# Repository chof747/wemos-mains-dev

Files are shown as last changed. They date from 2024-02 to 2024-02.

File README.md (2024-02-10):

## Board to combine a Wemos D1 Mini with a mini power supply

This is a small board that can take a Wemos D1 Mini  together with a 5V mini power supply to obtain a W-Lan microcontroller board with IO pins able to put e.g. in a switch box and power it
directly from mains

It contains the following elements:

- WeMos D1 Mini (or any other microcontroller board that has the same pin configuration)
- A 600mA/5V (3W) power supply 
- A 2x12 pinheader providing all GPIO Pins of the D1 mini in a suitable configuration
- Pull-Up Resistors for the SDA and SCL line
- Jumper Pins to select if the pullups should be used or not
- ByPass Capacitors for the 3V3 and GND lines in vicinity to the One-Wire and analog pin
- Screw Terminal to connect the board to mains

## Features

The breakout of the pins is designed in a way that it can support HATs of a certain form factor. So far I have designed the following HATs which you can find here:

- RJ11 Socket HAT [chof747/rj11-wemos-hat](https://github.com/chof747/rj11-wemos-hat)

## Revision History:

- **v1.0**: Initial version (filed for fabrication: 19.04.2023)
- **v1.1**: Revision 1 with corrected orientation of power supply and reduced ground plane to avoid collision with high voltage (filed for fabrication: 17.7.2023; First Assembly 06.10.2023)

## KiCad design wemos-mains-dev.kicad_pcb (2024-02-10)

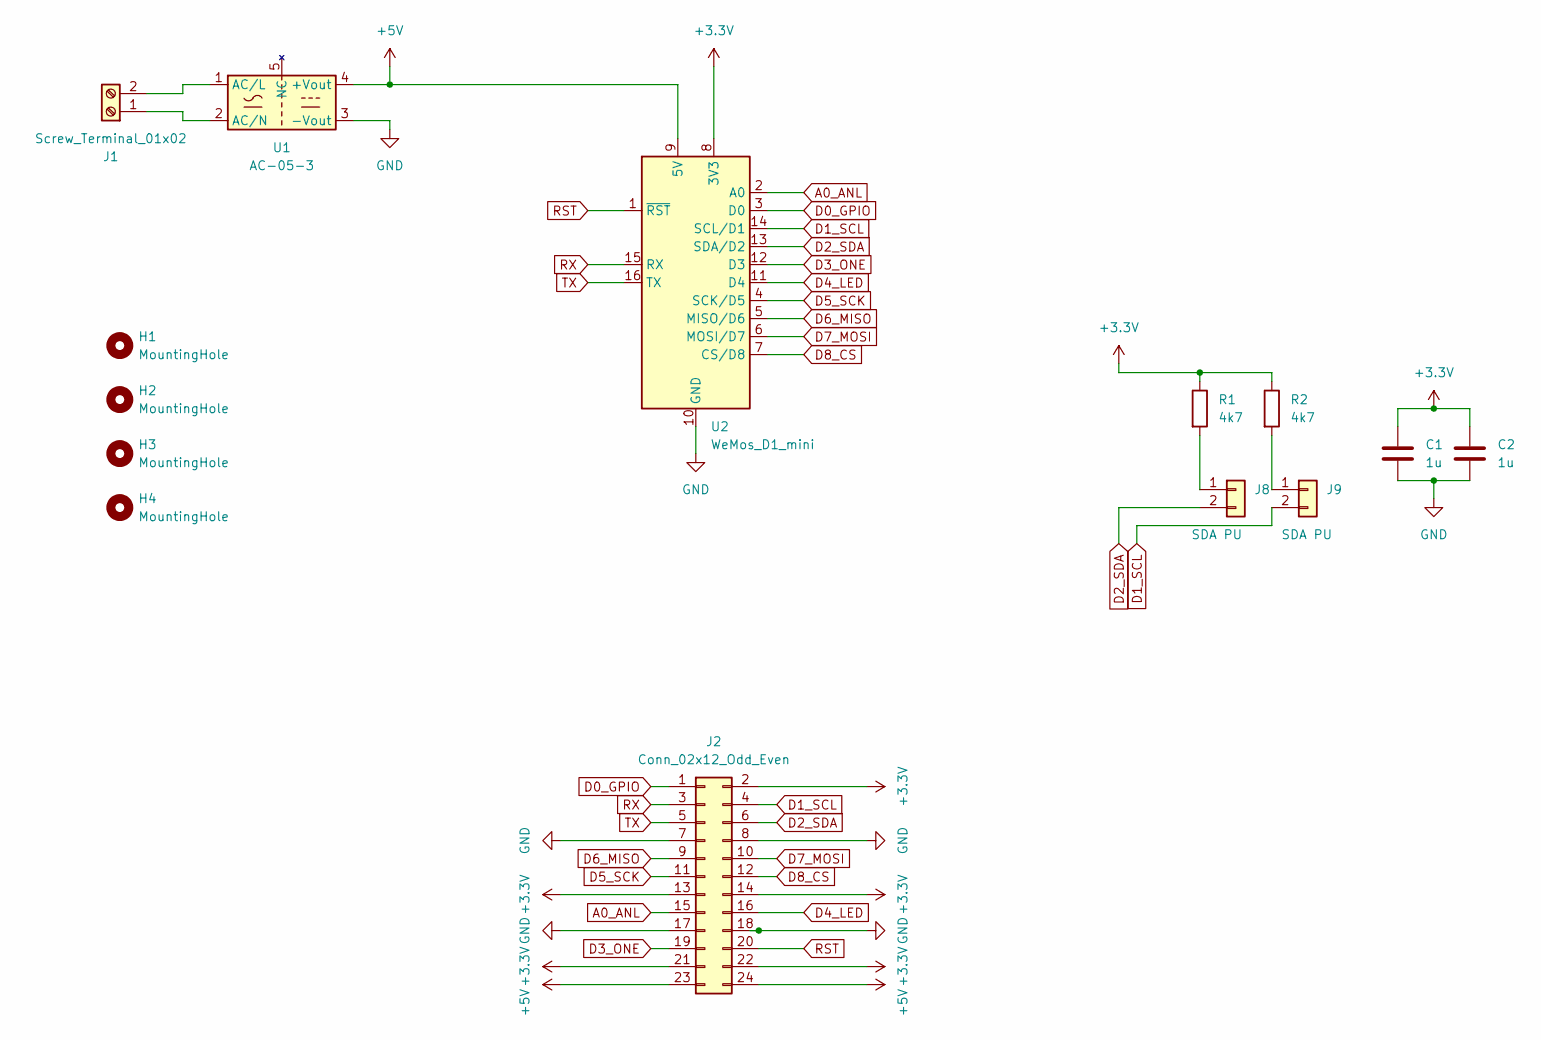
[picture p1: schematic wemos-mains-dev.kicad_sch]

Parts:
C1, C2: 1u; C_0603_1608Metric_Pad1.08x0.95mm_HandSolder
H1, H2, H3, H4: MountingHole; MountingHole_3.2mm_M3-smallBorder
J1: Screw_Terminal_01x02; TerminalBlock_bornier-2_P5.08mm
J2: Conn_02x12_Odd_Even; PinSocket_2x12_P2.54mm_Vertical
J8, J9: SDA PU; PinHeader_1x02_P2.54mm_Vertical
R1, R2: 4k7; R_0603_1608Metric_Pad0.98x0.95mm_HandSolder
U1: AC-05-3; AZDelivery AC-05-3
U2: WeMos_D1_mini; WEMOS_D1_mini_light

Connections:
+3.3V: C1.1, C2.1, J2.2, J2.13, J2.14, J2.21, J2.22, R1.1, R2.1, U2.8 (3V3)
+5V: J2.23, J2.24, U1.4 (+Vout), U2.9 (5V)
A0_ANL: J2.15, U2.2 (A0)
D0_GPIO: J2.1, U2.3 (D0)
D1_SCL: J2.4, J9.2, U2.14 (SCL/D1)
D2_SDA: J2.6, J8.2, U2.13 (SDA/D2)
D3_ONE: J2.19, U2.12 (D3)
D4_LED: J2.16, U2.11 (D4)
D5_SCK: J2.11, U2.4 (SCK/D5)
D6_MISO: J2.9, U2.5 (MISO/D6)
D7_MOSI: J2.10, U2.6 (MOSI/D7)
D8_CS: J2.12, U2.7 (CS/D8)
GND: C1.2, C2.2, J2.7, J2.8, J2.17, J2.18, U1.3 (-Vout), U2.10 (GND)
unnamed: J1.1, U1.2 (AC/N)
unnamed: J1.2, U1.1 (AC/L)
unnamed: J8.1, R1.2
unnamed: J9.1, R2.2
RST: J2.20, U2.1 (~RST)
RX: J2.3, U2.15 (RX)
TX: J2.5, U2.16 (TX)

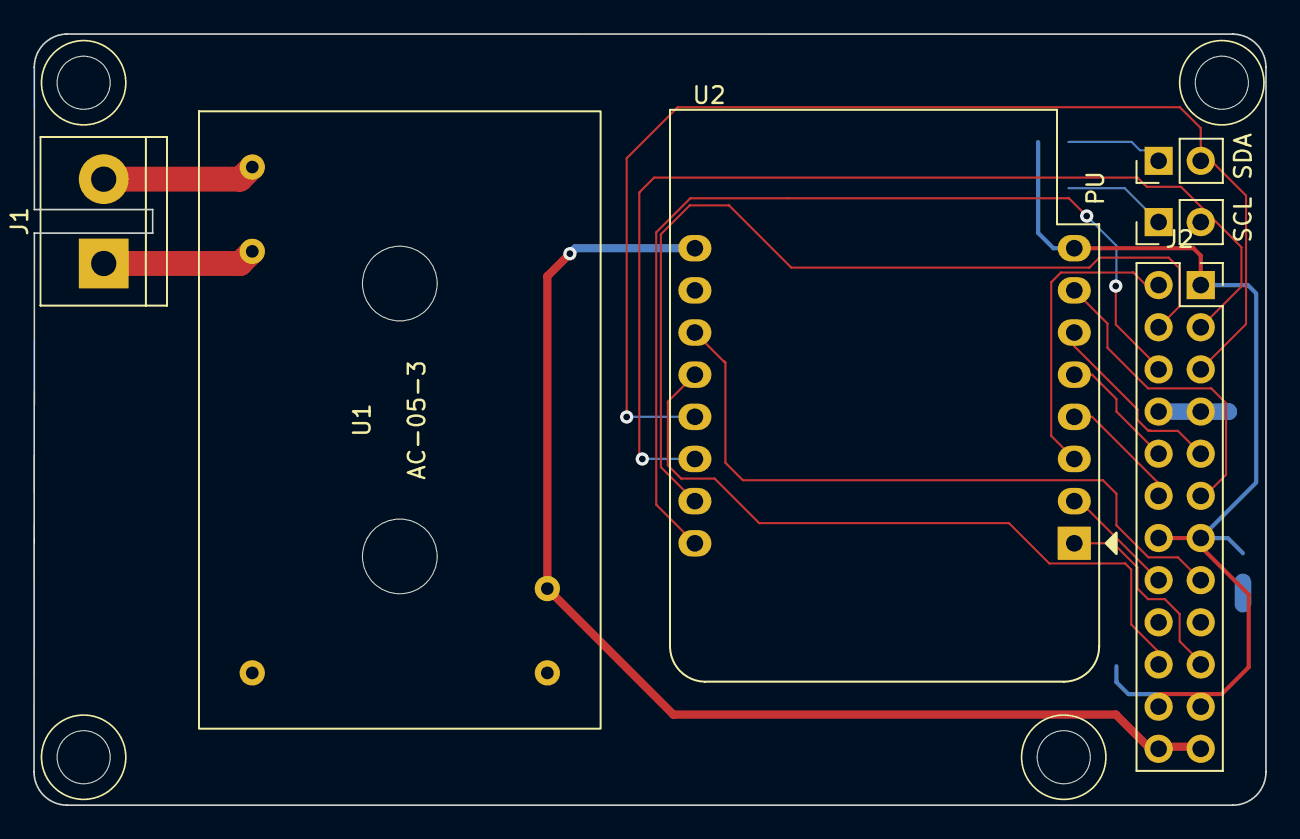
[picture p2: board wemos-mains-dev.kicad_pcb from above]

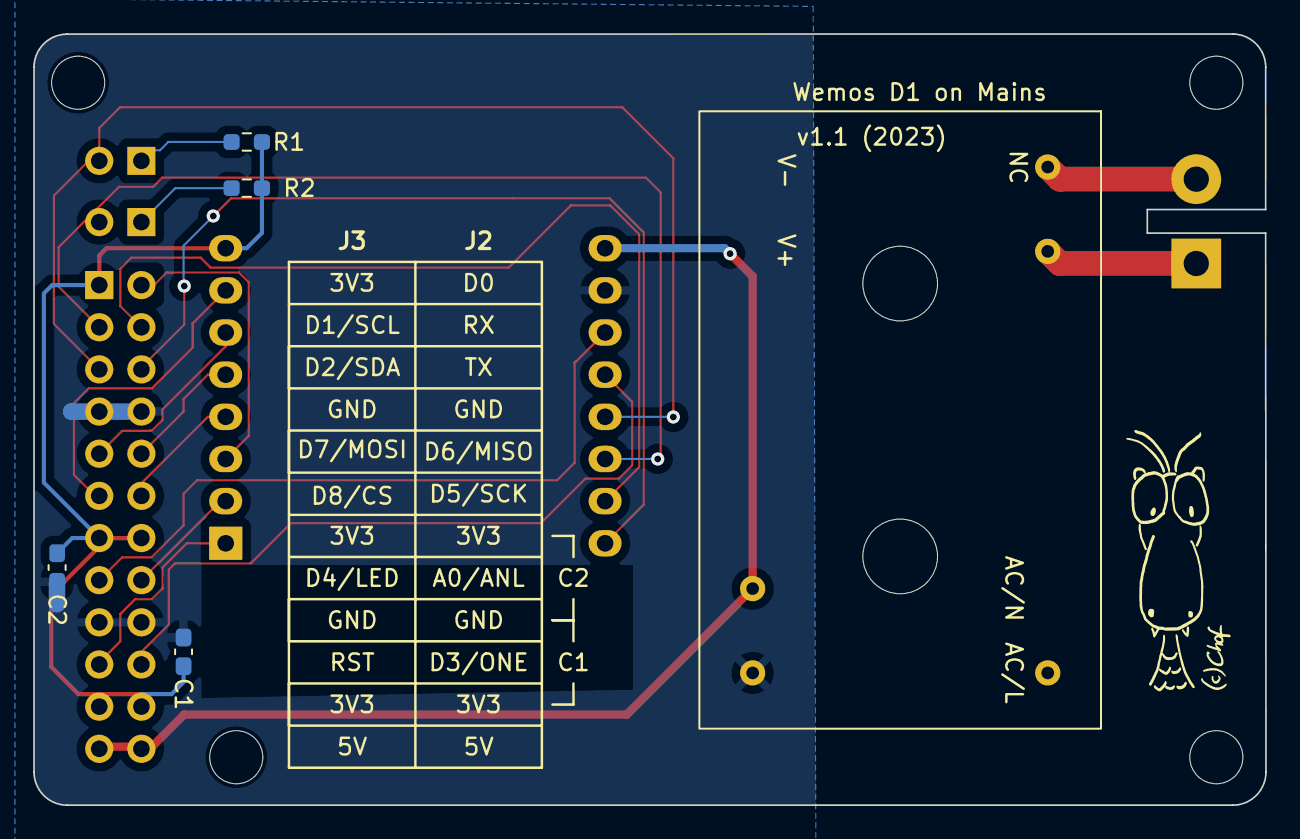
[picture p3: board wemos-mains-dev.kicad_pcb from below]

Board: 2 copper layers, 74.2 x 46.5 mm, 14 parts (4 on the bottom side), 20 nets.

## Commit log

2023-04-19 Version 1.0 including basic set of features for first PT board
    [template-project.kicad_pcb, template-project.kicad_sch, wemos-mains-dev.kicad_pcb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]
2023-04-20 Changed pinheader for breakout to 02x12
    [wemos-mains-dev.kicad_pcb, wemos-mains-dev.kicad_sch]
2023-04-20 Revision 1 commit
    - Added suitable README file
    - Minor updates on board regarding Front Fab layer (no impact on board)
    [wemos-mains-dev.kicad_pcb]
2023-04-27 Updated template for KiCAD 7
    [wemos-mains-dev.kicad_pcb, wemos-mains-dev.kicad_sch]
2023-05-04 Corrections for rev. 1
    - Corrected orientation of power supply footprint
    - Reduced ground plane to low voltage side
    [wemos-mains-dev.kicad_pcb, wemos-mains-dev.kicad_sch]
2023-07-11 made a space between high volt contacts
    [wemos-mains-dev.kicad_pcb]
2023-10-06 First Assembly rev. 1.1
2024-02-10 changed hat socket to socket from header
    [wemos-mains-dev.kicad_pcb, wemos-mains-dev.kicad_sch]
